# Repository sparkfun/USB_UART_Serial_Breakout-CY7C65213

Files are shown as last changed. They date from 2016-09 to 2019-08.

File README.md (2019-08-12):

SparkFun USB UART Serial Breakout - CY7C65213
==================

SparkFun USB UART Serial Breakout - CY7C65213 (https://www.sparkfun.com/products/13830)

[*SparkFun USB UART Serial Breakout - CY7C65213*](https://www.sparkfun.com/products/13830)

The CY7C65213 USB to UART serial breakout is designed to provide users with a means to access all available I/O pins on the IC, and to provide a 6-pin UART header that is compatible with other SparkFun breakout boards. This breakout has a microUSB connector and other support circuitry to get the IC quickly up and running.

Repository Contents
-------------------

* **/hardware** - Eagle PCB layout files
* **/Production** - Files to support SparkFun production

Documentation
-------------------

[Hookup Guide](https://learn.sparkfun.com/tutorials/sparkfun-usb-uart-breakout-cy7c65213-hookup-guide) - Basic hookup guide

License Information
-------------------

All contents of this repository are released under [Creative Commons Share-alike 4.0](http://creativecommons.org/licenses/by-sa/4.0/).

Authors: Mike Hord @ SparkFun Electonics

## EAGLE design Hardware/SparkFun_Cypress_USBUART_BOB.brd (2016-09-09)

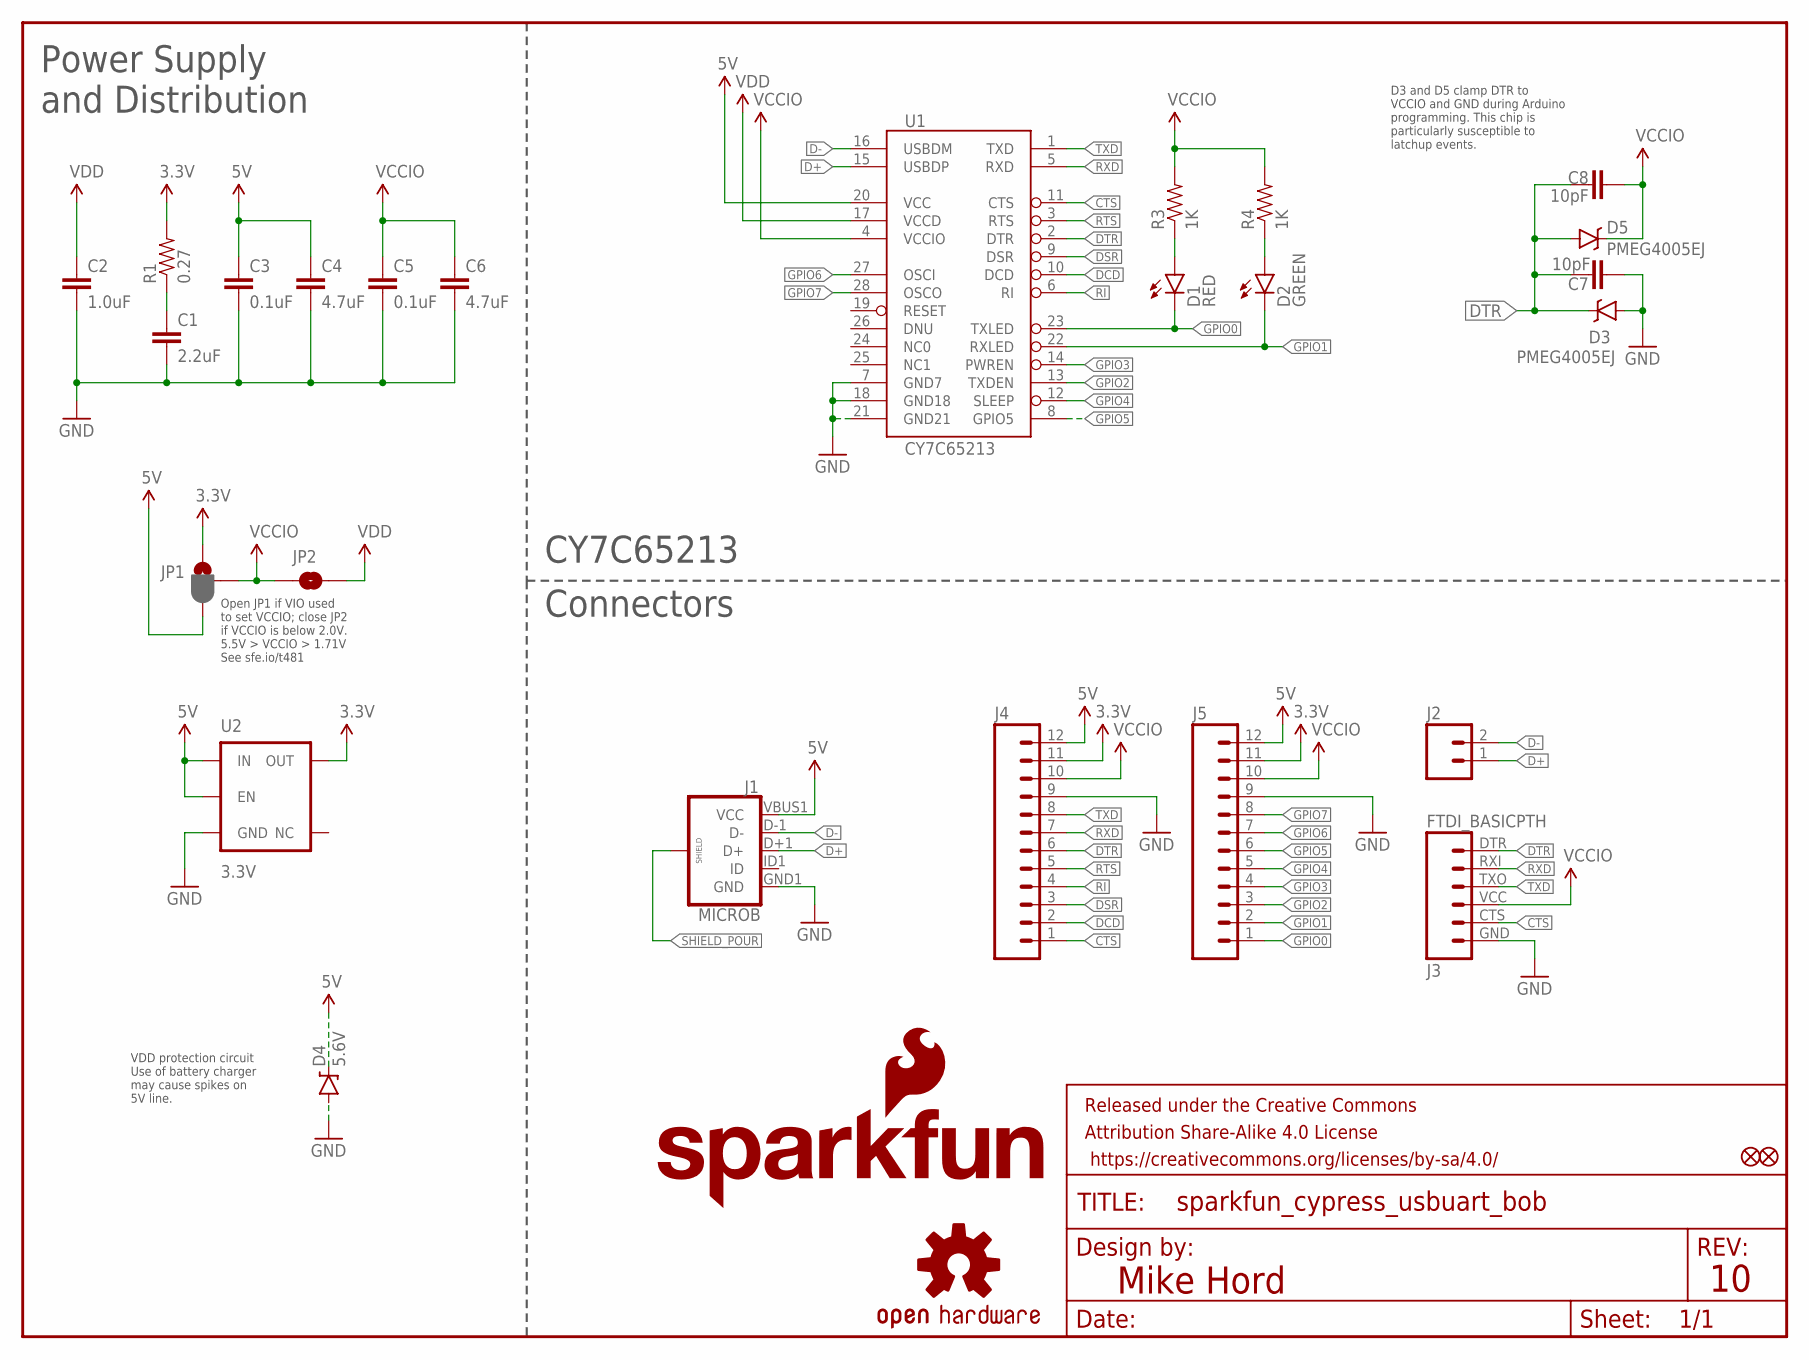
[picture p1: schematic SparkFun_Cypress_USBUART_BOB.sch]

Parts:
C1: 2.2uF; 0603-CAP
C2: 1.0uF; 0603-CAP
C3, C5: 0.1uF; 0603-CAP
C4, C6: 4.7uF; 1206-CAP
C7, C8: 10pF; 0603-CAP
D1: RED; LED-0603
D2: GREEN; LED-0603
D3, D5: PMEG4005EJ; SOD-323
D4: 5.6V; SOD-323
FD1, FD2: FIDUCIALUFIDUCIAL; MICRO-FIDUCIAL
FRAME1: FRAME-LETTER; CREATIVE_COMMONS
J1: MICROB; USB-B-MICRO-SMD_V03
J2: M02PTH; 1X02
J3: FTDI_BASICPTH; FTDI_BASIC
J4, J5: M12PTH; 1X12
JP1: JUMPER-PAD-3-2OF3_NC_BY_PASTE; PAD-JUMPER-3-2OF3_NC_BY_PASTE_YES_SILK_FULL_BOX
JP2: JUMPER-PAD-2-NOYES_SILK; PAD-JUMPER-2-NO_YES_SILK
LOGO1: SFE_LOGO_NAME_FLAME.1_INCH; SFE_LOGO_NAME_FLAME_.1
LOGO2: OSHW-LOGOS; OSHW-LOGO-S
R1: 0.27; 0603-RES
R3, R4: 1K; 0603-RES
U1: CY7C65213; SSOP28DB
U2: 3.3V; SOT23-5

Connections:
3.3V: J4.11, J5.11, JP1.1, R1.2, U2.5 (OUT)
5V: C3.1, C4.1, D4.C, J1.VBUS1 (VCC), J4.12, J5.12, JP1.3, U1.20 (VCC), U2.1 (IN), U2.3 (EN)
CTS: J3.CTS (5), J4.1, U1.11 (CTS)
D+: J1.D+1 (D+), J2.1, U1.15 (USBDP)
D-: J1.D-1 (D-), J2.2, U1.16 (USBDM)
DCD: J4.2, U1.10 (DCD)
DSR: J4.3, U1.9 (DSR)
DTR: C7.1, C8.1, D3.C, D5.A, J3.DTR (1), J4.6, U1.2 (DTR)
GND: C1.2, C2.2, C3.2, C4.2, C5.2, C6.2, C7.2, D3.A, D4.A, J1.GND1 (GND), J3.GND (6), J4.9, J5.9, U1.7 (GND7), U1.18 (GND18), U1.21 (GND21), U2.2 (GND)
GPIO0: D1.C, J5.1, U1.23 (TXLED)
GPIO1: D2.C, J5.2, U1.22 (RXLED)
GPIO2: J5.3, U1.13 (TXDEN)
GPIO3: J5.4, U1.14 (PWREN)
GPIO4: J5.5, U1.12 (SLEEP)
GPIO5: J5.6, U1.8 (GPIO5)
GPIO6: J5.7, U1.27 (OSCI)
GPIO7: J5.8, U1.28 (OSCO)
unnamed: C1.1, R1.1
unnamed: D2.A, R4.1
unnamed: D1.A, R3.1
NC1: U1.25 (NC1)
RI: J4.4, U1.6 (RI)
RTS: J4.5, U1.3 (RTS)
RXD: J3.RXI (2), J4.7, U1.5 (RXD)
SHIELD_POUR: J1.SHIELD1 (SHIELD), J1.SHIELD2 (SHIELD), J1.SHIELD3 (SHIELD)
TXD: J3.TXO (3), J4.8, U1.1 (TXD)
VCCIO: C5.1, C6.1, C8.2, D5.C, J3.VCC (4), J4.10, J5.10, JP1.2, JP2.1, R3.2, R4.2, U1.4 (VCCIO)
VDD: C2.1, JP2.2, U1.17 (VCCD)

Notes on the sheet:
Mike Hord
Open JP1 if VIO used to set VCCIO; close JP2 if VCCIO is below 2.0V. 5.5V > VCCIO > 1.71V See sfe.io/t481
Power Supply and Distribution
Connectors
CY7C65213
D3 and D5 clamp DTR to VCCIO and GND during Arduino programming. This chip is particularly susceptible to latchup events.
VDD protection circuit Use of battery charger may cause spikes on 5V line.

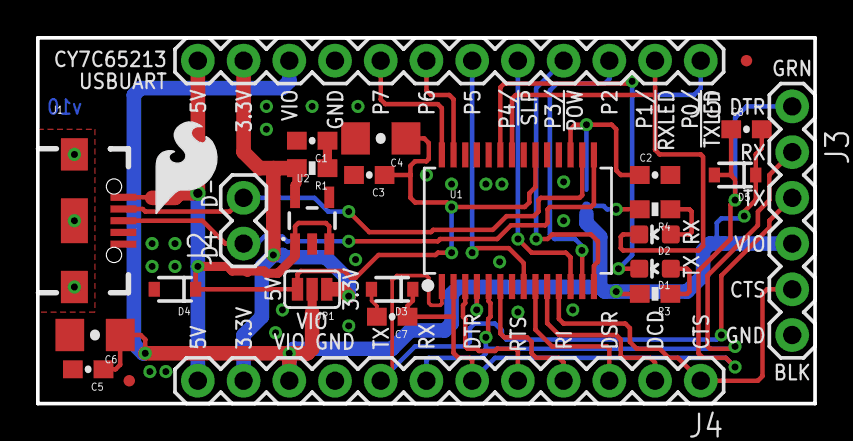
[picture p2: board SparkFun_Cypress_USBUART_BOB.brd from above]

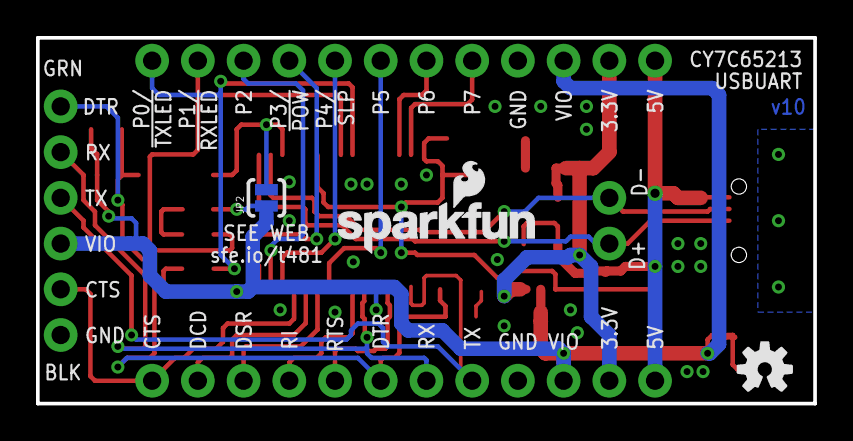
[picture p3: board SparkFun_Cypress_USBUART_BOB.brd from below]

Board: 2 copper layers, 43.2 x 20.3 mm, 31 parts (3 on the bottom side), 27 nets.

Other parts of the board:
LOGO5: SFE_LOGO_FLAME.2_INCH; SFE_LOGO_FLAME_.2

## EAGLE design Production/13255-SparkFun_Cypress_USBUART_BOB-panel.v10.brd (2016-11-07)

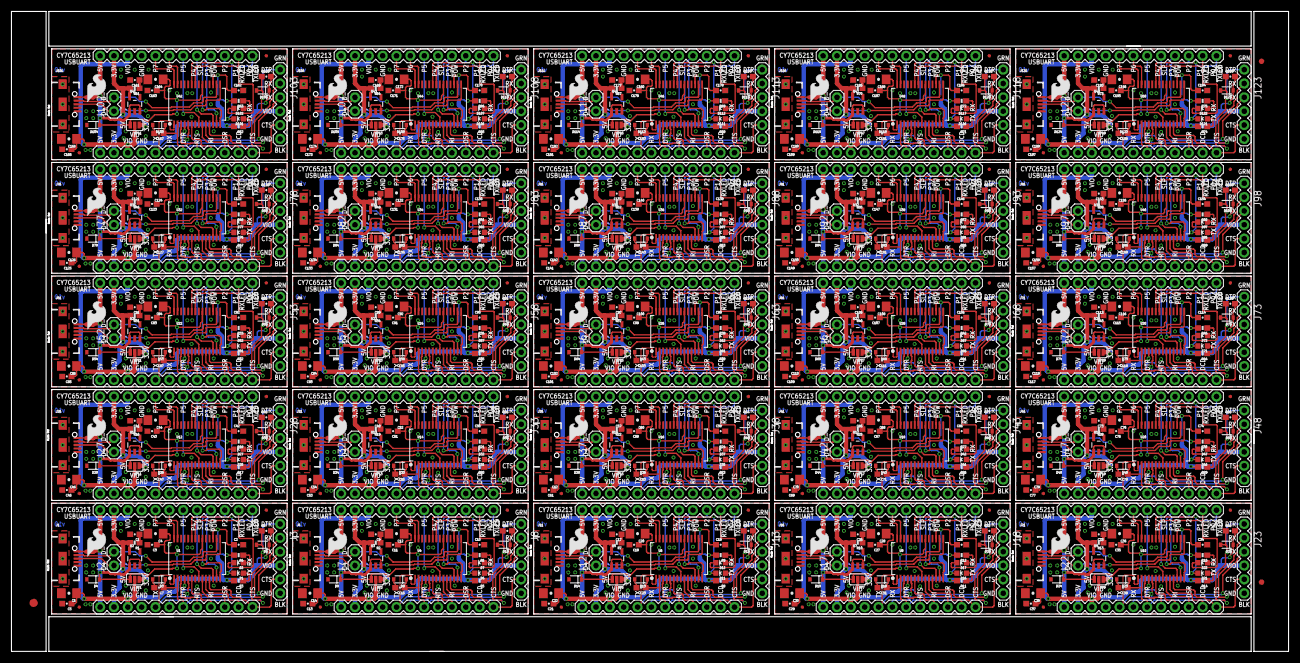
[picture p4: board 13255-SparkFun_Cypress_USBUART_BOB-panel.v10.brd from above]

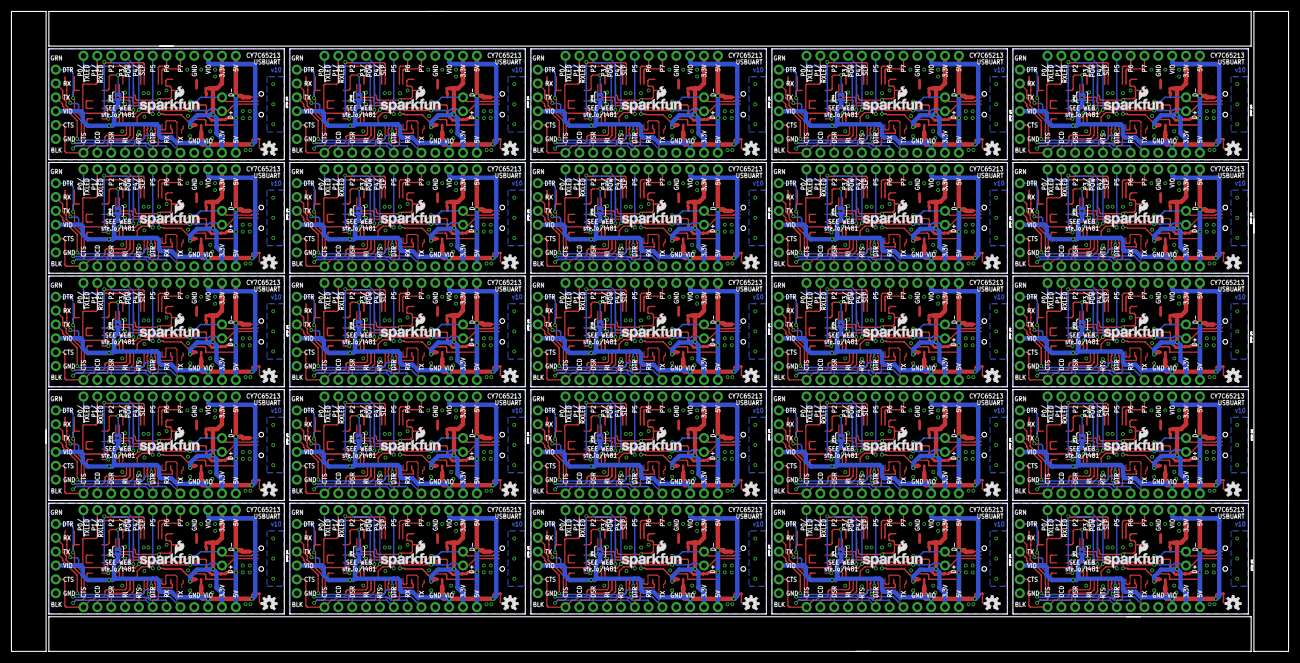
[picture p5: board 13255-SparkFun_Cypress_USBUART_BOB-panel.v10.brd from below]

Board: 2 copper layers, 234.2 x 117.3 mm, 753 parts (75 on the bottom side), 675 nets.

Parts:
C1, C9, C17, C25, C33, C41, C49, C57, C65, C73, C81, C89, C97, C105, C113, C121, C129, C137, C145, C153, C161, C169, C177, C185, C193: 2.2uF; 0603-CAP
C2, C10, C18, C26, C34, C42, C50, C58, C66, C74, C82, C90, C98, C106, C114, C122, C130, C138, C146, C154, C162, C170, C178, C186, C194: 1.0uF; 0603-CAP
C3, C5, C11, C13, C19, C21, C27, C29, C35, C37, C43, C45, C51, C53, C59, C61, C67, C69, C75, C77, C83, C85, C91, C93, C99, C101, C107, C109, C115, C117, C123, C125, C131, C133, C139, C141, C147, C149, C155, C157, C163, C165, C171, C173, C179, C181, C187, C189, C195, C197: 0.1uF; 0603-CAP
C4, C6, C12, C14, C20, C22, C28, C30, C36, C38, C44, C46, C52, C54, C60, C62, C68, C70, C76, C78, C84, C86, C92, C94, C100, C102, C108, C110, C116, C118, C124, C126, C132, C134, C140, C142, C148, C150, C156, C158, C164, C166, C172, C174, C180, C182, C188, C190, C196, C198: 4.7uF; 1206-CAP
C7, C8, C15, C16, C23, C24, C31, C32, C39, C40, C47, C48, C55, C56, C63, C64, C71, C72, C79, C80, C87, C88, C95, C96, C103, C104, C111, C112, C119, C120, C127, C128, C135, C136, C143, C144, C151, C152, C159, C160, C167, C168, C175, C176, C183, C184, C191, C192, C199, C200: 10pF; 0603-CAP
D1, D6, D11, D16, D21, D26, D31, D36, D41, D46, D51, D56, D61, D66, D71, D76, D81, D86, D91, D96, D101, D106, D111, D116, D121: RED; LED-0603
D2, D7, D12, D17, D22, D27, D32, D37, D42, D47, D52, D57, D62, D67, D72, D77, D82, D87, D92, D97, D102, D107, D112, D117, D122: GREEN; LED-0603
D3, D5, D8, D10, D13, D15, D18, D20, D23, D25, D28, D30, D33, D35, D38, D40, D43, D45, D48, D50, D53, D55, D58, D60, D63, D65, D68, D70, D73, D75, D78, D80, D83, D85, D88, D90, D93, D95, D98, D100, D103, D105, D108, D110, D113, D115, D118, D120, D123, D125: PMEG4005EJ; SOD-323
D4, D9, D14, D19, D24, D29, D34, D39, D44, D49, D54, D59, D64, D69, D74, D79, D84, D89, D94, D99, D104, D109, D114, D119, D124: 5.6V; SOD-323
E$1: FIDUCIAL-1.5X3
E$7, E$8: FIDUCIAL-1X2
FD1, FD2, FD3, FD4, FD5, FD6, FD7, FD8, FD9, FD10, FD11, FD12, FD13, FD14, FD15, FD16, FD17, FD18, FD19, FD20, FD21, FD22, FD23, FD24, FD25, FD26, FD27, FD28, FD29, FD30, FD31, FD32, FD33, FD34, FD35, FD36, FD37, FD38, FD39, FD40, FD41, FD42, FD43, FD44, FD45, FD46, FD47, FD48, FD49, FD50: FIDUCIALUFIDUCIAL; MICRO-FIDUCIAL
J1, J6, J11, J16, J21, J26, J31, J36, J41, J46, J51, J56, J61, J66, J71, J76, J81, J86, J91, J96, J101, J106, J111, J116, J121: MICROB; USB-B-MICRO-SMD_V03
J2, J7, J12, J17, J22, J27, J32, J37, J42, J47, J52, J57, J62, J67, J72, J77, J82, J87, J92, J97, J102, J107, J112, J117, J122: 1X02
J3, J8, J13, J18, J23, J28, J33, J38, J43, J48, J53, J58, J63, J68, J73, J78, J83, J88, J93, J98, J103, J108, J113, J118, J123: FTDI_BASICPTH; FTDI_BASIC
J4, J5, J9, J10, J14, J15, J19, J20, J24, J25, J29, J30, J34, J35, J39, J40, J44, J45, J49, J50, J54, J55, J59, J60, J64, J65, J69, J70, J74, J75, J79, J80, J84, J85, J89, J90, J94, J95, J99, J100, J104, J105, J109, J110, J114, J115, J119, J120, J124, J125: 1X12
JP1, JP3, JP5, JP7, JP9, JP11, JP13, JP15, JP17, JP19, JP21, JP23, JP25, JP27, JP29, JP31, JP33, JP35, JP37, JP39, JP41, JP43, JP45, JP47, JP49: JUMPER-PAD-3-2OF3_NC_BY_PASTE; PAD-JUMPER-3-2OF3_NC_BY_PASTE_YES_SILK_FULL_BOX
JP2, JP4, JP6, JP8, JP10, JP12, JP14, JP16, JP18, JP20, JP22, JP24, JP26, JP28, JP30, JP32, JP34, JP36, JP38, JP40, JP42, JP44, JP46, JP48, JP50: JUMPER-PAD-2-NOYES_SILK; PAD-JUMPER-2-NO_YES_SILK
LOGO1, LOGO3, LOGO7, LOGO10, LOGO13, LOGO16, LOGO19, LOGO22, LOGO25, LOGO28, LOGO31, LOGO34, LOGO37, LOGO40, LOGO43, LOGO46, LOGO49, LOGO52, LOGO55, LOGO58, LOGO61, LOGO64, LOGO67, LOGO70, LOGO73: SFE_LOGO_NAME_FLAME.1_INCH; SFE_LOGO_NAME_FLAME_.1
LOGO2, LOGO6, LOGO9, LOGO12, LOGO15, LOGO18, LOGO21, LOGO24, LOGO27, LOGO30, LOGO33, LOGO36, LOGO39, LOGO42, LOGO45, LOGO48, LOGO51, LOGO54, LOGO57, LOGO60, LOGO63, LOGO66, LOGO69, LOGO72, LOGO75: OSHW-LOGOS; OSHW-LOGO-S
LOGO4, LOGO5, LOGO8, LOGO11, LOGO14, LOGO17, LOGO20, LOGO23, LOGO26, LOGO29, LOGO32, LOGO35, LOGO38, LOGO41, LOGO44, LOGO47, LOGO50, LOGO53, LOGO56, LOGO59, LOGO62, LOGO65, LOGO68, LOGO71, LOGO74: SFE_LOGO_FLAME.2_INCH; SFE_LOGO_FLAME_.2
R1, R2, R7, R10, R13, R16, R19, R22, R25, R28, R31, R34, R37, R40, R43, R46, R49, R52, R55, R58, R61, R64, R67, R70, R73: 0.27; 0603-RES
R3, R4, R5, R6, R8, R9, R11, R12, R14, R15, R17, R18, R20, R21, R23, R24, R26, R27, R29, R30, R32, R33, R35, R36, R38, R39, R41, R42, R44, R45, R47, R48, R50, R51, R53, R54, R56, R57, R59, R60, R62, R63, R65, R66, R68, R69, R71, R72, R74, R75: 1K; 0603-RES
U1, U4, U6, U8, U10, U12, U14, U16, U18, U20, U22, U24, U26, U28, U30, U32, U34, U36, U38, U40, U42, U44, U46, U48, U50: CY7C65213; SSOP28DB
U2, U3, U5, U7, U9, U11, U13, U15, U17, U19, U21, U23, U25, U27, U29, U31, U33, U35, U37, U39, U41, U43, U45, U47, U49: 3.3V; SOT23-5

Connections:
3.3V: J4.11, J5.11, JP1.1, R1.2, U2.5
3.3V1: J9.11, J10.11, JP3.1, R2.2, U3.5
3.3V2: J14.11, J15.11, JP5.1, R7.2, U5.5
3.3V3: J19.11, J20.11, JP7.1, R10.2, U7.5
3.3V4: J24.11, J25.11, JP9.1, R13.2, U9.5
3.3V5: J29.11, J30.11, JP11.1, R16.2, U11.5
3.3V6: J34.11, J35.11, JP13.1, R19.2, U13.5
3.3V7: J39.11, J40.11, JP15.1, R22.2, U15.5
3.3V8: J44.11, J45.11, JP17.1, R25.2, U17.5
3.3V9: J49.11, J50.11, JP19.1, R28.2, U19.5
3.3V10: J54.11, J55.11, JP21.1, R31.2, U21.5
3.3V11: J59.11, J60.11, JP23.1, R34.2, U23.5
3.3V12: J64.11, J65.11, JP25.1, R37.2, U25.5
3.3V13: J69.11, J70.11, JP27.1, R40.2, U27.5
3.3V14: J74.11, J75.11, JP29.1, R43.2, U29.5
3.3V15: J79.11, J80.11, JP31.1, R46.2, U31.5
3.3V16: J84.11, J85.11, JP33.1, R49.2, U33.5
3.3V17: J89.11, J90.11, JP35.1, R52.2, U35.5
3.3V18: J94.11, J95.11, JP37.1, R55.2, U37.5
3.3V19: J99.11, J100.11, JP39.1, R58.2, U39.5
3.3V20: J104.11, J105.11, JP41.1, R61.2, U41.5
3.3V21: J109.11, J110.11, JP43.1, R64.2, U43.5
3.3V22: J114.11, J115.11, JP45.1, R67.2, U45.5
3.3V23: J119.11, J120.11, JP47.1, R70.2, U47.5
3.3V24: J124.11, J125.11, JP49.1, R73.2, U49.5
5V: C3.1, C4.1, D4.C, J1.VBUS1, J4.12, J5.12, JP1.3, U1.20, U2.1, U2.3
5V1: C11.1, C12.1, D9.C, J6.VBUS1, J9.12, J10.12, JP3.3, U3.1, U3.3, U4.20
5V2: C19.1, C20.1, D14.C, J11.VBUS1, J14.12, J15.12, JP5.3, U5.1, U5.3, U6.20
5V3: C27.1, C28.1, D19.C, J16.VBUS1, J19.12, J20.12, JP7.3, U7.1, U7.3, U8.20
5V4: C35.1, C36.1, D24.C, J21.VBUS1, J24.12, J25.12, JP9.3, U9.1, U9.3, U10.20
5V5: C43.1, C44.1, D29.C, J26.VBUS1, J29.12, J30.12, JP11.3, U11.1, U11.3, U12.20
5V6: C51.1, C52.1, D34.C, J31.VBUS1, J34.12, J35.12, JP13.3, U13.1, U13.3, U14.20
5V7: C59.1, C60.1, D39.C, J36.VBUS1, J39.12, J40.12, JP15.3, U15.1, U15.3, U16.20
5V8: C67.1, C68.1, D44.C, J41.VBUS1, J44.12, J45.12, JP17.3, U17.1, U17.3, U18.20
5V9: C75.1, C76.1, D49.C, J46.VBUS1, J49.12, J50.12, JP19.3, U19.1, U19.3, U20.20
5V10: C83.1, C84.1, D54.C, J51.VBUS1, J54.12, J55.12, JP21.3, U21.1, U21.3, U22.20
5V11: C91.1, C92.1, D59.C, J56.VBUS1, J59.12, J60.12, JP23.3, U23.1, U23.3, U24.20
5V12: C99.1, C100.1, D64.C, J61.VBUS1, J64.12, J65.12, JP25.3, U25.1, U25.3, U26.20
5V13: C107.1, C108.1, D69.C, J66.VBUS1, J69.12, J70.12, JP27.3, U27.1, U27.3, U28.20
5V14: C115.1, C116.1, D74.C, J71.VBUS1, J74.12, J75.12, JP29.3, U29.1, U29.3, U30.20
5V15: C123.1, C124.1, D79.C, J76.VBUS1, J79.12, J80.12, JP31.3, U31.1, U31.3, U32.20
5V16: C131.1, C132.1, D84.C, J81.VBUS1, J84.12, J85.12, JP33.3, U33.1, U33.3, U34.20
5V17: C139.1, C140.1, D89.C, J86.VBUS1, J89.12, J90.12, JP35.3, U35.1, U35.3, U36.20
5V18: C147.1, C148.1, D94.C, J91.VBUS1, J94.12, J95.12, JP37.3, U37.1, U37.3, U38.20
5V19: C155.1, C156.1, D99.C, J96.VBUS1, J99.12, J100.12, JP39.3, U39.1, U39.3, U40.20
5V20: C163.1, C164.1, D104.C, J101.VBUS1, J104.12, J105.12, JP41.3, U41.1, U41.3, U42.20
5V21: C171.1, C172.1, D109.C, J106.VBUS1, J109.12, J110.12, JP43.3, U43.1, U43.3, U44.20
5V22: C179.1, C180.1, D114.C, J111.VBUS1, J114.12, J115.12, JP45.3, U45.1, U45.3, U46.20
5V23: C187.1, C188.1, D119.C, J116.VBUS1, J119.12, J120.12, JP47.3, U47.1, U47.3, U48.20
5V24: C195.1, C196.1, D124.C, J121.VBUS1, J124.12, J125.12, JP49.3, U49.1, U49.3, U50.20
CTS: J3.CTS, J4.1, U1.11
CTS1: J8.CTS, J9.1, U4.11
CTS2: J13.CTS, J14.1, U6.11
CTS3: J18.CTS, J19.1, U8.11
CTS4: J23.CTS, J24.1, U10.11
CTS5: J28.CTS, J29.1, U12.11
CTS6: J33.CTS, J34.1, U14.11
CTS7: J38.CTS, J39.1, U16.11
CTS8: J43.CTS, J44.1, U18.11
CTS9: J48.CTS, J49.1, U20.11
CTS10: J53.CTS, J54.1, U22.11
CTS11: J58.CTS, J59.1, U24.11
CTS12: J63.CTS, J64.1, U26.11
CTS13: J68.CTS, J69.1, U28.11
CTS14: J73.CTS, J74.1, U30.11
CTS15: J78.CTS, J79.1, U32.11
CTS16: J83.CTS, J84.1, U34.11
CTS17: J88.CTS, J89.1, U36.11
CTS18: J93.CTS, J94.1, U38.11
CTS19: J98.CTS, J99.1, U40.11
CTS20: J103.CTS, J104.1, U42.11
CTS21: J108.CTS, J109.1, U44.11
CTS22: J113.CTS, J114.1, U46.11
CTS23: J118.CTS, J119.1, U48.11
CTS24: J123.CTS, J124.1, U50.11
D+: J1.D+1, J2.1, U1.15
D+1: J6.D+1, J7.1, U4.15
D+2: J11.D+1, J12.1, U6.15
D+3: J16.D+1, J17.1, U8.15
D+4: J21.D+1, J22.1, U10.15
D+5: J26.D+1, J27.1, U12.15
D+6: J31.D+1, J32.1, U14.15
D+7: J36.D+1, J37.1, U16.15
D+8: J41.D+1, J42.1, U18.15
D+9: J46.D+1, J47.1, U20.15
D+10: J51.D+1, J52.1, U22.15
D+11: J56.D+1, J57.1, U24.15
D+12: J61.D+1, J62.1, U26.15
D+13: J66.D+1, J67.1, U28.15
D+14: J71.D+1, J72.1, U30.15
D+15: J76.D+1, J77.1, U32.15
D+16: J81.D+1, J82.1, U34.15
D+17: J86.D+1, J87.1, U36.15
D+18: J91.D+1, J92.1, U38.15
D+19: J96.D+1, J97.1, U40.15
D+20: J101.D+1, J102.1, U42.15
D+21: J106.D+1, J107.1, U44.15
D+22: J111.D+1, J112.1, U46.15
D+23: J116.D+1, J117.1, U48.15
D+24: J121.D+1, J122.1, U50.15
D-: J1.D-1, J2.2, U1.16
D-1: J6.D-1, J7.2, U4.16
D-2: J11.D-1, J12.2, U6.16
D-3: J16.D-1, J17.2, U8.16
D-4: J21.D-1, J22.2, U10.16
D-5: J26.D-1, J27.2, U12.16
D-6: J31.D-1, J32.2, U14.16
D-7: J36.D-1, J37.2, U16.16
D-8: J41.D-1, J42.2, U18.16
D-9: J46.D-1, J47.2, U20.16
D-10: J51.D-1, J52.2, U22.16
D-11: J56.D-1, J57.2, U24.16
D-12: J61.D-1, J62.2, U26.16
D-13: J66.D-1, J67.2, U28.16
D-14: J71.D-1, J72.2, U30.16
D-15: J76.D-1, J77.2, U32.16
D-16: J81.D-1, J82.2, U34.16
D-17: J86.D-1, J87.2, U36.16
D-18: J91.D-1, J92.2, U38.16
D-19: J96.D-1, J97.2, U40.16
D-20: J101.D-1, J102.2, U42.16
D-21: J106.D-1, J107.2, U44.16
D-22: J111.D-1, J112.2, U46.16
D-23: J116.D-1, J117.2, U48.16
D-24: J121.D-1, J122.2, U50.16
DCD: J4.2, U1.10
DCD1: J9.2, U4.10
DCD2: J14.2, U6.10
DCD3: J19.2, U8.10
DCD4: J24.2, U10.10
DCD5: J29.2, U12.10
DCD6: J34.2, U14.10
DCD7: J39.2, U16.10
DCD8: J44.2, U18.10
DCD9: J49.2, U20.10
DCD10: J54.2, U22.10
DCD11: J59.2, U24.10
DCD12: J64.2, U26.10
DCD13: J69.2, U28.10
DCD14: J74.2, U30.10
DCD15: J79.2, U32.10
DCD16: J84.2, U34.10
DCD17: J89.2, U36.10
DCD18: J94.2, U38.10
DCD19: J99.2, U40.10
DCD20: J104.2, U42.10
DCD21: J109.2, U44.10
DCD22: J114.2, U46.10
DCD23: J119.2, U48.10
DCD24: J124.2, U50.10
DSR: J4.3, U1.9
DSR1: J9.3, U4.9
DSR2: J14.3, U6.9
DSR3: J19.3, U8.9
DSR4: J24.3, U10.9
DSR5: J29.3, U12.9
DSR6: J34.3, U14.9
DSR7: J39.3, U16.9
DSR8: J44.3, U18.9
DSR9: J49.3, U20.9
DSR10: J54.3, U22.9
DSR11: J59.3, U24.9
DSR12: J64.3, U26.9
DSR13: J69.3, U28.9
DSR14: J74.3, U30.9
DSR15: J79.3, U32.9
DSR16: J84.3, U34.9
DSR17: J89.3, U36.9
DSR18: J94.3, U38.9
DSR19: J99.3, U40.9
DSR20: J104.3, U42.9
DSR21: J109.3, U44.9
DSR22: J114.3, U46.9
DSR23: J119.3, U48.9
DSR24: J124.3, U50.9
DTR: C7.1, C8.1, D3.C, D5.A, J3.DTR, J4.6, U1.2
DTR1: C15.1, C16.1, D8.C, D10.A, J8.DTR, J9.6, U4.2
DTR2: C23.1, C24.1, D13.C, D15.A, J13.DTR, J14.6, U6.2
DTR3: C31.1, C32.1, D18.C, D20.A, J18.DTR, J19.6, U8.2
DTR4: C39.1, C40.1, D23.C, D25.A, J23.DTR, J24.6, U10.2
DTR5: C47.1, C48.1, D28.C, D30.A, J28.DTR, J29.6, U12.2
DTR6: C55.1, C56.1, D33.C, D35.A, J33.DTR, J34.6, U14.2
DTR7: C63.1, C64.1, D38.C, D40.A, J38.DTR, J39.6, U16.2
DTR8: C71.1, C72.1, D43.C, D45.A, J43.DTR, J44.6, U18.2
DTR9: C79.1, C80.1, D48.C, D50.A, J48.DTR, J49.6, U20.2
DTR10: C87.1, C88.1, D53.C, D55.A, J53.DTR, J54.6, U22.2
DTR11: C95.1, C96.1, D58.C, D60.A, J58.DTR, J59.6, U24.2
DTR12: C103.1, C104.1, D63.C, D65.A, J63.DTR, J64.6, U26.2
DTR13: C111.1, C112.1, D68.C, D70.A, J68.DTR, J69.6, U28.2
DTR14: C119.1, C120.1, D73.C, D75.A, J73.DTR, J74.6, U30.2
DTR15: C127.1, C128.1, D78.C, D80.A, J78.DTR, J79.6, U32.2
DTR16: C135.1, C136.1, D83.C, D85.A, J83.DTR, J84.6, U34.2
DTR17: C143.1, C144.1, D88.C, D90.A, J88.DTR, J89.6, U36.2
DTR18: C151.1, C152.1, D93.C, D95.A, J93.DTR, J94.6, U38.2
DTR19: C159.1, C160.1, D98.C, D100.A, J98.DTR, J99.6, U40.2
DTR20: C167.1, C168.1, D103.C, D105.A, J103.DTR, J104.6, U42.2
DTR21: C175.1, C176.1, D108.C, D110.A, J108.DTR, J109.6, U44.2
DTR22: C183.1, C184.1, D113.C, D115.A, J113.DTR, J114.6, U46.2
DTR23: C191.1, C192.1, D118.C, D120.A, J118.DTR, J119.6, U48.2
DTR24: C199.1, C200.1, D123.C, D125.A, J123.DTR, J124.6, U50.2
GND: C1.2, C2.2, C3.2, C4.2, C5.2, C6.2, C7.2, D3.A, D4.A, J1.GND1, J3.GND, J4.9, J5.9, U1.7, U1.18, U1.21, U2.2
GND1: C9.2, C10.2, C11.2, C12.2, C13.2, C14.2, C15.2, D8.A, D9.A, J6.GND1, J8.GND, J9.9, J10.9, U3.2, U4.7, U4.18, U4.21
GND2: C17.2, C18.2, C19.2, C20.2, C21.2, C22.2, C23.2, D13.A, D14.A, J11.GND1, J13.GND, J14.9, J15.9, U5.2, U6.7, U6.18, U6.21
GND3: C25.2, C26.2, C27.2, C28.2, C29.2, C30.2, C31.2, D18.A, D19.A, J16.GND1, J18.GND, J19.9, J20.9, U7.2, U8.7, U8.18, U8.21
GND4: C33.2, C34.2, C35.2, C36.2, C37.2, C38.2, C39.2, D23.A, D24.A, J21.GND1, J23.GND, J24.9, J25.9, U9.2, U10.7, U10.18, U10.21
GND5: C41.2, C42.2, C43.2, C44.2, C45.2, C46.2, C47.2, D28.A, D29.A, J26.GND1, J28.GND, J29.9, J30.9, U11.2, U12.7, U12.18, U12.21
GND6: C49.2, C50.2, C51.2, C52.2, C53.2, C54.2, C55.2, D33.A, D34.A, J31.GND1, J33.GND, J34.9, J35.9, U13.2, U14.7, U14.18, U14.21
GND7: C57.2, C58.2, C59.2, C60.2, C61.2, C62.2, C63.2, D38.A, D39.A, J36.GND1, J38.GND, J39.9, J40.9, U15.2, U16.7, U16.18, U16.21
GND8: C65.2, C66.2, C67.2, C68.2, C69.2, C70.2, C71.2, D43.A, D44.A, J41.GND1, J43.GND, J44.9, J45.9, U17.2, U18.7, U18.18, U18.21
GND9: C73.2, C74.2, C75.2, C76.2, C77.2, C78.2, C79.2, D48.A, D49.A, J46.GND1, J48.GND, J49.9, J50.9, U19.2, U20.7, U20.18, U20.21
GND10: C81.2, C82.2, C83.2, C84.2, C85.2, C86.2, C87.2, D53.A, D54.A, J51.GND1, J53.GND, J54.9, J55.9, U21.2, U22.7, U22.18, U22.21
GND11: C89.2, C90.2, C91.2, C92.2, C93.2, C94.2, C95.2, D58.A, D59.A, J56.GND1, J58.GND, J59.9, J60.9, U23.2, U24.7, U24.18, U24.21
GND12: C97.2, C98.2, C99.2, C100.2, C101.2, C102.2, C103.2, D63.A, D64.A, J61.GND1, J63.GND, J64.9, J65.9, U25.2, U26.7, U26.18, U26.21
GND13: C105.2, C106.2, C107.2, C108.2, C109.2, C110.2, C111.2, D68.A, D69.A, J66.GND1, J68.GND, J69.9, J70.9, U27.2, U28.7, U28.18, U28.21
GND14: C113.2, C114.2, C115.2, C116.2, C117.2, C118.2, C119.2, D73.A, D74.A, J71.GND1, J73.GND, J74.9, J75.9, U29.2, U30.7, U30.18, U30.21
GND15: C121.2, C122.2, C123.2, C124.2, C125.2, C126.2, C127.2, D78.A, D79.A, J76.GND1, J78.GND, J79.9, J80.9, U31.2, U32.7, U32.18, U32.21
GND16: C129.2, C130.2, C131.2, C132.2, C133.2, C134.2, C135.2, D83.A, D84.A, J81.GND1, J83.GND, J84.9, J85.9, U33.2, U34.7, U34.18, U34.21
GND17: C137.2, C138.2, C139.2, C140.2, C141.2, C142.2, C143.2, D88.A, D89.A, J86.GND1, J88.GND, J89.9, J90.9, U35.2, U36.7, U36.18, U36.21
GND18: C145.2, C146.2, C147.2, C148.2, C149.2, C150.2, C151.2, D93.A, D94.A, J91.GND1, J93.GND, J94.9, J95.9, U37.2, U38.7, U38.18, U38.21
GND19: C153.2, C154.2, C155.2, C156.2, C157.2, C158.2, C159.2, D98.A, D99.A, J96.GND1, J98.GND, J99.9, J100.9, U39.2, U40.7, U40.18, U40.21
GND20: C161.2, C162.2, C163.2, C164.2, C165.2, C166.2, C167.2, D103.A, D104.A, J101.GND1, J103.GND, J104.9, J105.9, U41.2, U42.7, U42.18, U42.21
GND21: C169.2, C170.2, C171.2, C172.2, C173.2, C174.2, C175.2, D108.A, D109.A, J106.GND1, J108.GND, J109.9, J110.9, U43.2, U44.7, U44.18, U44.21
GND22: C177.2, C178.2, C179.2, C180.2, C181.2, C182.2, C183.2, D113.A, D114.A, J111.GND1, J113.GND, J114.9, J115.9, U45.2, U46.7, U46.18, U46.21
GND23: C185.2, C186.2, C187.2, C188.2, C189.2, C190.2, C191.2, D118.A, D119.A, J116.GND1, J118.GND, J119.9, J120.9, U47.2, U48.7, U48.18, U48.21
GND24: C193.2, C194.2, C195.2, C196.2, C197.2, C198.2, C199.2, D123.A, D124.A, J121.GND1, J123.GND, J124.9, J125.9, U49.2, U50.7, U50.18, U50.21
GPIO0: D1.C, J5.1, U1.23
GPIO1: D2.C, J5.2, U1.22
GPIO2: J5.3, U1.13
GPIO3: J5.4, U1.14
GPIO4: J5.5, U1.12
GPIO5: J5.6, U1.8
GPIO6: J5.7, U1.27
GPIO7: J5.8, U1.28
GPIO8: J10.7, U4.27
GPIO9: J10.8, U4.28
GPIO10: D6.C, J10.1, U4.23
GPIO11: D7.C, J10.2, U4.22
GPIO12: J10.4, U4.14
GPIO13: J10.3, U4.13
GPIO14: J10.5, U4.12
GPIO15: J10.6, U4.8
GPIO16: J15.7, U6.27
GPIO17: J15.8, U6.28
GPIO18: D11.C, J15.1, U6.23
GPIO19: D12.C, J15.2, U6.22
GPIO20: J15.4, U6.14
GPIO21: J15.3, U6.13
GPIO22: J15.5, U6.12
GPIO23: J15.6, U6.8
GPIO24: J20.7, U8.27
GPIO25: J20.8, U8.28
GPIO26: D16.C, J20.1, U8.23
GPIO27: D17.C, J20.2, U8.22
GPIO28: J20.4, U8.14
GPIO29: J20.3, U8.13
GPIO30: J20.5, U8.12
GPIO31: J20.6, U8.8
GPIO32: J25.7, U10.27
GPIO33: J25.8, U10.28
GPIO34: D21.C, J25.1, U10.23
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

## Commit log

2016-02-15 Ready for QC review
    [SparkFun_Cypress_USBUART_BOB.brd, SparkFun_Cypress_USBUART_BOB.sch]
2016-02-15 Fixed another insufficiently bent trace
    [SparkFun_Cypress_USBUART_BOB.brd]
2016-03-29 Rotate a couple of parts, add 10k resistor, v02
    [SparkFun_Cypress_USBUART_BOB.brd, SparkFun_Cypress_USBUART_BOB.sch]
2016-06-28 Changes from review incorporated
    [SparkFun_Cypress_USBUART_BOB.brd, SparkFun_Cypress_USBUART_BOB.sch]
2016-08-02 Changed version number for reds
    [SparkFun_Cypress_USBUART_BOB.brd, SparkFun_Cypress_USBUART_BOB.sch]
2016-08-18 Revert to v02.
    Revert "Changed version number for reds"
    This reverts commit 640f5162c93cb70f6f1d384f505e534c75df1209.
    [SparkFun_Cypress_USBUART_BOB.brd, SparkFun_Cypress_USBUART_BOB.sch]
2016-08-18 Revert to v02
    [SparkFun_Cypress_USBUART_BOB.brd, SparkFun_Cypress_USBUART_BOB.sch]
2016-08-19 Feedback from group review, add clamping diodes
    [SparkFun_Cypress_USBUART_BOB.brd, SparkFun_Cypress_USBUART_BOB.sch]
2016-08-19 Remove 15-ohm resistor in power line
    [SparkFun_Cypress_USBUART_BOB.brd, SparkFun_Cypress_USBUART_BOB.sch]
2016-08-22 Changes from group review
    [SparkFun_Cypress_USBUART_BOB.brd]
2016-09-09 Update to v10, ready for reds
    [SparkFun_Cypress_USBUART_BOB.brd, SparkFun_Cypress_USBUART_BOB.sch]

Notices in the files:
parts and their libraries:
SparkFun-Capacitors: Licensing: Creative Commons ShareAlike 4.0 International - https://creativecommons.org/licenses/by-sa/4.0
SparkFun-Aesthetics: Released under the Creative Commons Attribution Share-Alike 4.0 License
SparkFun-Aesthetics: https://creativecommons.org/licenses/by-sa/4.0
